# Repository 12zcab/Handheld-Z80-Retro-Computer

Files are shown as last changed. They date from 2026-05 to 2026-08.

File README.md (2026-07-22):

# A Handheld Z80 Retro Computer







Hello Im 12zcab from Hong Kong and I designed this Z80 Retro Computer :DD

# Zine Page
https://www.figma.com/design/0DzeSIebLkugrNq00bVcSF/Untitled?node-id=0-1&t=Gd1BAF2dvagKk23V-1
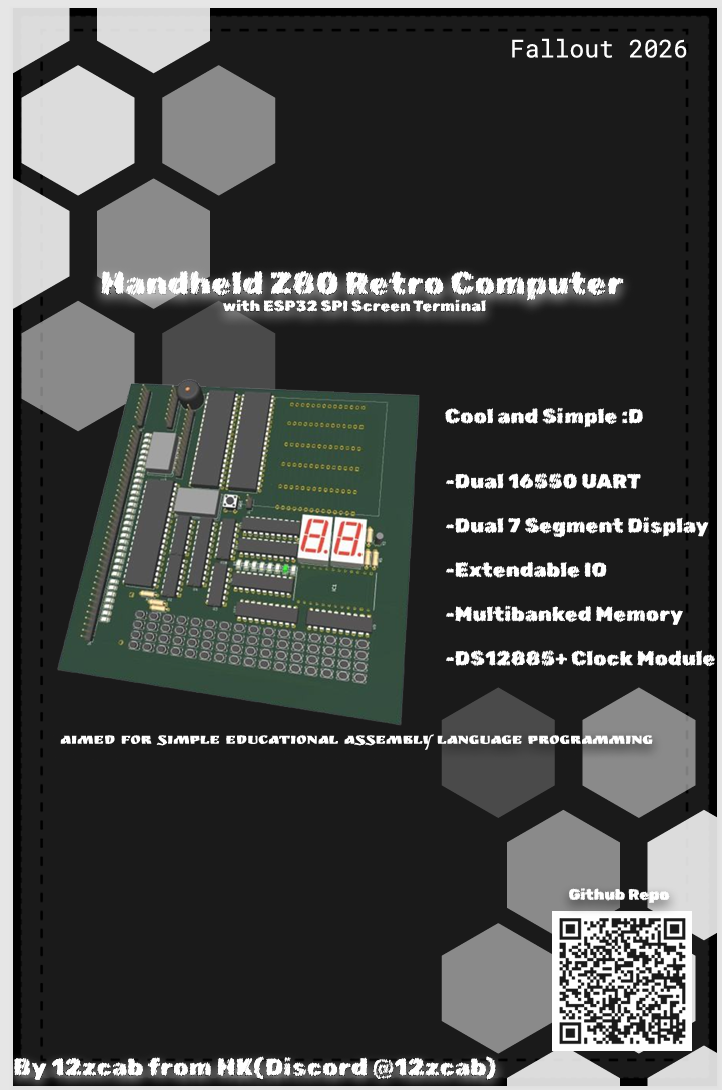
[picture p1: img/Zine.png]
Zine


# Images
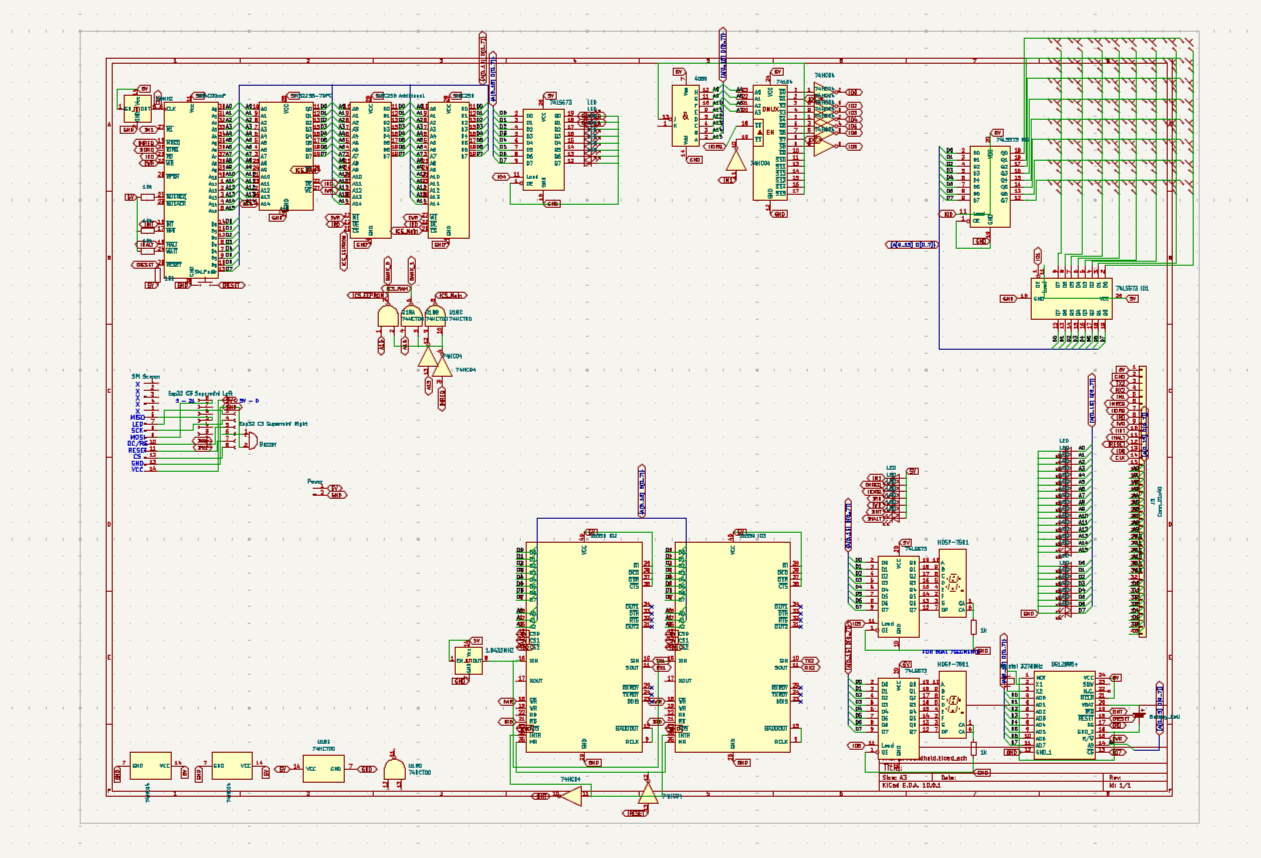
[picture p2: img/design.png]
Design

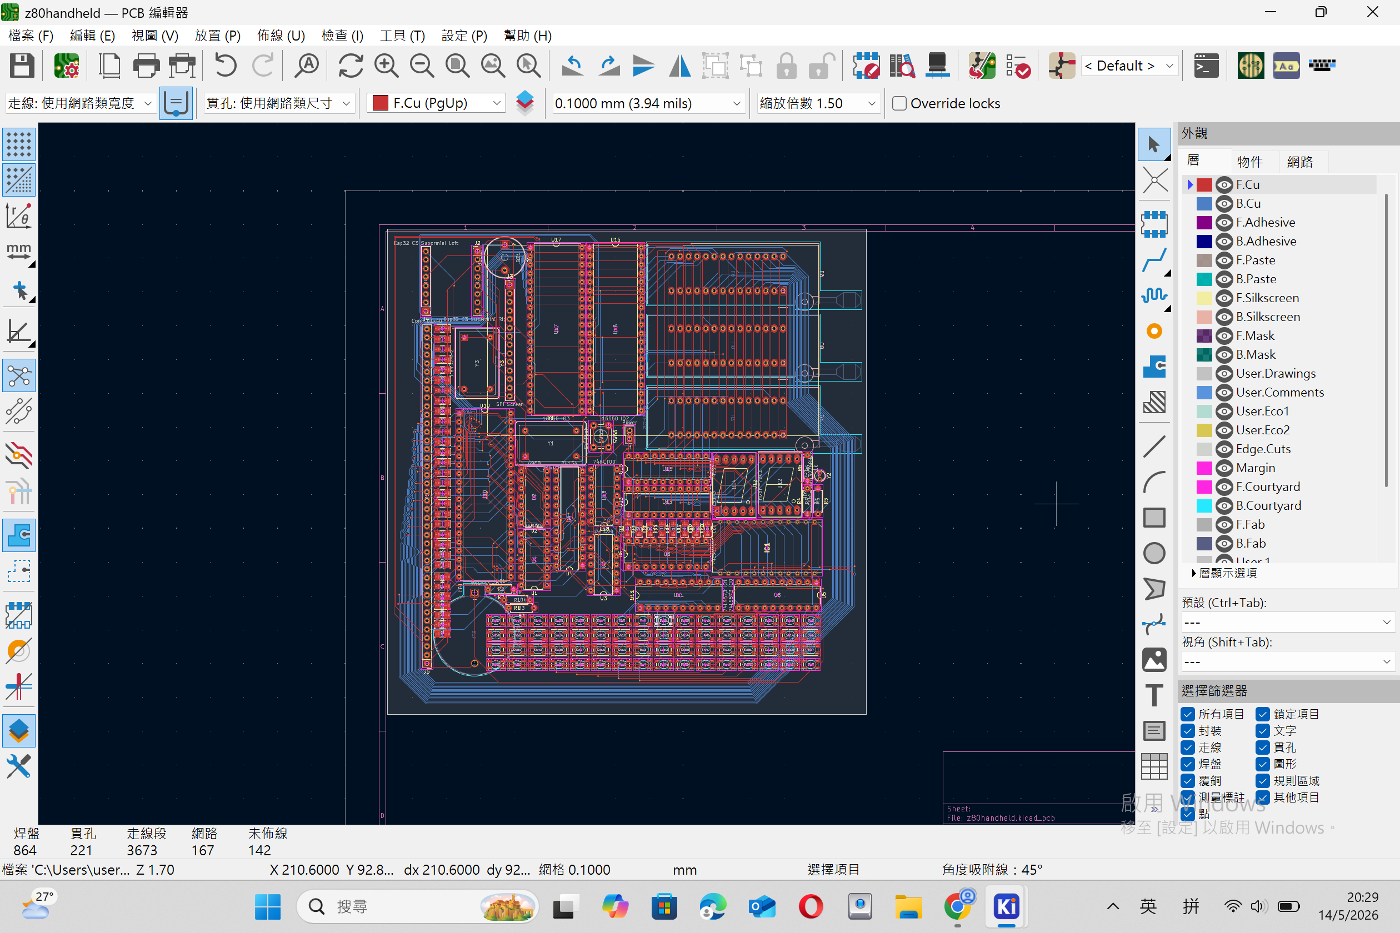
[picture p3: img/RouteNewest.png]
Route

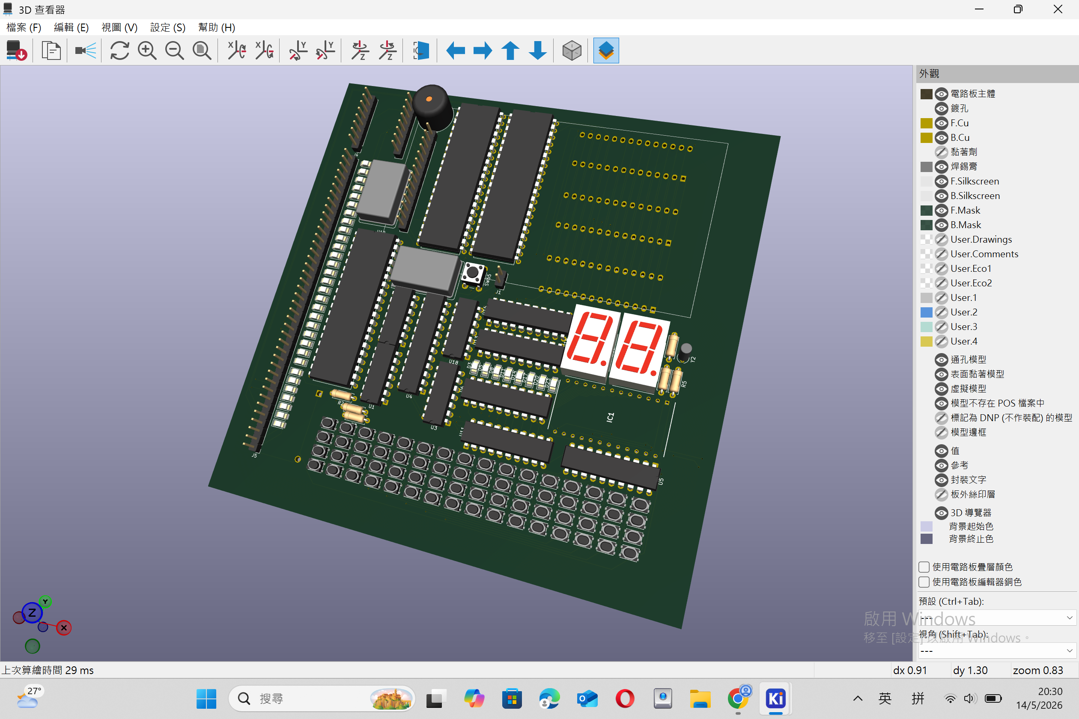
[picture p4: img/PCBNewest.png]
PCB


# What is this?
This is a portable handheld computer made with z80 customized for assembly language programming and simplified system for educational purpose.
The computer comtains a Z80 cpu,a SPI screen,a Esp32 C3 Supermini and 2 EEPROM slot,a RAM slot,a buzzer,some leds,2 7segments and a extendable port for IO.
The computer support Dual-UART communication, one with the Esp32 and one for extending.
# What it does?
It just let you run simple programs on it and let you bring it anywhere!
My final goal is to write a fully functional Operating System and make it as simple as possible on this computer!
With the ESP32 C3 Supermini connected through UART,you can draw on SPI screen and output characters just like connected to a VT100 Terminal (for old computers)
With the Buzzer,7segments and the keyboard also with the extendable port,you can build alsome retro coding projects on this old-fashion Cyberdeck :D
# Why it exists?
Erm it all started when I found a video about old pokemon games and i started to play Gen 1 pokemon games on emulators(Red Version).
I found it a really amazing experience to have play a game with greyscale and 8 bit musics.
Then I asked my parents and found that we actually have a real gameboy athome!!
I then started to research on how gameboy works and study on the Disassembled PokeRed gameboy assembly code on github and I was shocked on how elegance it is the original assembly code.
Then I learnt the gbz80 instruction set,also the boot rom of the gameboy,then also 8086,8051,8085 and z80 assembly.
I followed a youtube video and built my first z80 computer and started to do a few assembly programming on it and yah its really fun [Ytlink](https://youtu.be/A0VpPRWrqHc?si=ajm_OGpBwFbzzyzW).
I recently found Fallout Event on HackClub and instantly found this a great oppertunity to design my own real z80 computer that is simple and workable.

# Basic Structure
##Memory Map
| Address | Compoenent | Function |
|----|----|----|
|0x0000 - 0x7FFF| EEPROM | Executable Code of Operating System |
|0x8000 - 0xFEFF| RAM or EEPROM | Multibanked External EEPROM and RAM |
|0xFF00 - 0xFFFF| IO Outputs | for Output,UART,and also other Extension Usage |
|----|----|----|

# Compoenents

## Main Compoenents
| Name | Usage | Quantity |
|----|----|----|
| Z84C00xxP | The CPU of the Computer | 1 |
| ESP32 C3 Supermini | The Micro Controller Board for Serial Output Processing | 1 |
| 3.5inch SPI Screen 14Pin| For Displaying Serial Output | 1 |
| DS12885+ Clock Module | Clock Module For Z80 | 1 |
| 62256 | 32k RAM for Z80 | 1 |
| 28C256 | 32k EEPROM for External file and Bootloader and Applications | 2 |
| HDSP-7501 | 7 Segment Display for Z80 Output | 2 |
| 16550 | UART Communication IC for Z80 IO | 2 |
| PTS 810 SMD Button | Keyboard Input for Z80 | 64 |
| 4 Pin 6mm Switch | Reset Button for Z80 | 1 |
| LED SMD 1206 | SMD LED with internal resistor for Signal and Data Bus displaying | 39 |
| Buzzer | D12mm height 9.5mm with RM7.6mm Buzzer for ESP32 C3 Supermini to Emit sound when receive specific serial input from Z80 | 1 |
| CR2032 battery holder | Battery for DS12885+ Clock Module | 1 |

## Logic Gates and ICs
| Name | Usage | Quantity |
|----|----|----|
| 74HC573 | A Registor for Input and Output and Multibanking | 5 |
| 74HC04 | Hex Logic Invertor for toggling High-Activate Signals and Low-Activate Signals | 2 |
| 4068 | 8 Input AND/NAND Logic Gate for IO Signal Filtering | 1 |
| 74154 | 4 to 16 Decoder for IOS Address Decoding | 1 |
| 74HC00 | Quad NAND Gate | 2 |

## Crystals
| Name | Usage | Quantity |
|----|----|----|
| 4 Pin Crystals | 20MHz and 1.8432MHz for CPU and UART ic respectively | 2 |
| 2 Pin Crystal | 32768Hz for DS12885+ Clock Module | 1 |

## Resistors
| Name | Usage | Quantity |
|----|----|----|
| 1K resistor | 7 segment display resistor to prevent the display BURn :D | 2 |
| 10K resistor | Pull-up Resistors | 4 |

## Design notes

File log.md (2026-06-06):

Day1 18/4/2026

what will we do?

A Handheld Z80 based device with a LOTS of cool feature

1.IT MUST HAVE A KEYBOARD

2.IT HAVE A BIOS

3.IT HAVE A OPERATING SYSTEM

4.IT CAN LOAD BINARY FILES

5.IT CAN OUTPUT SOUND

6.IT MUST HAVE A SCREEN OFCOURSE EHHEEEEEEE(i think may be power with esp32 by reading UART(can receive ansi and VT350 commands))

7.IT BETTER CAN USE ESP32 TO DO INTERNET AND BLUETOOTH(DONT RELY TOO MUCH THOUGH...)

8.it can connect UART to computer :D 16550UART CHIP

9.better connect a tfcard

welp today lets make a really simple z80 circuit that can read from a eeprom when start :D

Memory

0x0000 to 0x7FFF 32kb BIOS + Program EEPROM (first half writable but second half is not.)

0x8000 to 0xFFFF 32kbRAM and 32kb ROM (Paged)

0xFF00 to 0xFFFsF Input and Output

what i need to do:

1.finish the Double UART

2.finish the SPI Screen and the esp32 c3 supermini

3\. finish the eeprom and ram

4\. write a simple bios

5.write a test program

6.add a 7segment led output io module

7.add some controllable pins for further extend

Day 2 19/4/2026

OHH YAEAH ITS OUR second day erm unfortunately i  dont really have much time today but nvm lets complete the UART thing first :D

what ive done:

1.UART

2.SPI screen

3.buzzer

4.Multibanking chip achieved with 573

what i need to do:

1\. finish the eeprom and ram
2\. write a simple bios
3\. write a test program
4\. add a 7segment led output io module
5\. add some controllable pins for further extend
6\. add status leds
7\. reset,halt,resume button(if needed i guess)
8\. controllable leds to fully utilize the 573 for multi banking

Part2

what ive done:

1.banking logic (totally)
2.searching for how z80 interrupt and halt and wait works.

what i need to do:

1. write a simple bios
2. write a test program
3. add some controllable pins for further extend
4. add status leds
5. reset,halt,resume button(if needed i guess)

Day 3 20/4/2026

what i will do today:

1. finish the status leds
2. add some controllable pins
3. reset halt and resume :D
 after some consideration i think i will just abandon the interrupt as humm I WRITE THE CODE I WRITE THE PROGRAMS NAD I DESIGN IT :D so i think i dont need them :DDDDD:D:D:DD:D:DDDDDDDDDDDDDDDDDDD

what ive done:
1. all of the schematics
2. layout the keyboard and led and spiscreen for the pcb

what i need to do:

1. write a simple bios
2. write a test program
3. layout the pcb

Day 4 21/4/2026

what ive done today:
1.layout the pcb
2.route the pcb(yah sorry with autoroute cuz my routing technique is kinda bad)

what i need to do:
1.write a bootloader
2.write a test program
3.write a program for esp32 to display serial datas

Day 5 22/4/2026

what ive done today:
1.rerouted the pcb (bruh Freeroute is terrible)
2.added the extension port
3.wrote something on the README.md

Day 6 23/4/2026

what ive done today:
1.edited the README.md to add the components list
2.autorouted AGAIIINNN with Electra and THATS WAS AMAZING OMG ITS SOOOOO COOL

Day 7 24/4/2026

what ive done today:
1.Wrote file for Programming on the Computer.
2.Fixed a wiring problem on PCB(Not Logic Gate Inverted for the interrupt Signal 16550) and reroute the wiring again.

Day 8 25/4/2026

what ive done today:
1.Finished the Programmer Manual

Day 9 1/5/2026

what ive done today:
1.Simplified the Multibank Circuit (Reduced SMD usage)
2.Rerouted the pcb again for the modification made
(I Tried EAGLE,AutoRoute,and even asked Ai to help me write a simple autoroute application but erm in the end i used electra :| electra is amazing...)

Day 10 3/5/2026

what ive done today:
Wrote a Script for the Video
Updated the BOM list
Updated the Documentation
Started to create the project video

Day 11 12 4/5/2026 and 5/5/2026

Human Reroute again and again :D

Day 13 7/5/2026
Wrote some assembly for Memory loading and 7 segment output and searched for how to write those assembly and tested on ASM80.com

Day 14-15 8/5/2026 9/5/2026
Continued to route the PCB

Day 16 11/5/2026
I realized the layout that I designed for the PCB was already wrong from the start...
the Layout is too terrible and too hard to route (why there are so many signals wiring that need to be routed across the whole board XDDDDDD)
Yah I redesigned the layout and i think now the layout is much more cleaner :D
the Interrupt Signals and the ReadWriteChipSelect signals are still hard to route though but the Data buses and Address buses are much better :D

Day 17 12/5/2026
humm actually the current layout is still not yet the best one but i think i will keep the current one and try to add more space for me to route by pushing a bit the edges :D

Day 1819 13-14/5/2026
FINISHED ROUTING PART and Re-Upload for review again :D

Day 20 6/6/2026
Edited the BOM and resubmitted for Review

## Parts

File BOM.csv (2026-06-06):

Type | Component Name | Usage | Quantity | Link | Price for 1 In RMB | Total Price In RMB | Total Price In USD
Main Component | Z84C00xxP | The CPU of the Computer | 1 | https://item.taobao.com/item.htm?id=761285443532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 | 4 | 4 | 0.6
Main Component | ESP32 C3 Supermini | The Micro Controller Board for Serial Output Processing | 1 | https://item.taobao.com/item.htm?id=811195319483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 | 9.2 | 9.2 | 1.38
Main Component | 3.5inch SPI Screen 14Pin | For Displaying Serial Output | 1 | https://item.taobao.com/item.htm?id=812167177326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 | 52.47 | 52.47 | 7.8705
Main Component | DS12885+ Clock Module | Clock Module For Z80 | 1 | https://item.taobao.com/item.htm?id=724760924535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 | 10 | 10 | 1.5
Main Component | 62256 | 32k RAM for Z80 | 1 | https://item.taobao.com/item.htm?id=762350642485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 | 3.8 | 3.8 | 0.57
Main Component | 28C256 | 32k EEPROM for External file and Bootloader and Applications | 2 | https://item.taobao.com/item.htm?id=772254803732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 | 11.9 | 23.8 | 3.57
Main Component | THT 7 Segment Display | 7 Segment Display for Z80 Output | 2 | https://item.taobao.com/item.htm?id=554338007716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 | 3.6 | 7.2 | 1.08
Main Component | 16550 UART | Communication IC for Z80 IO | 2 | https://item.taobao.com/item.htm?id=923571185900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 | 8.5 | 17 | 2.55
Main Component | PTS 810 SMD Button | Keyboard Input for Z80 | 64 | https://item.taobao.com/item.htm?id=942210332853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 | (for 70) | 17.5 | 2.625
Main Component | 4 Pin 6mm Switch | Reset Button for Z80 | 1 | https://item.taobao.com/item.htm?id=705965507255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 | 7.78 | 7.78 | 1.167
Main Component | LED SMD 1206 | SMD LED with internal resistor for Signal and Data Bus displaying | 39 | https://item.taobao.com/item.htm?ali_trackid=282_2fcfaf0dd0fba5e6a350743651408552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 | 2.43 (for 50) | 2.43 | 0.3645
Main Component | Buzzer D12mm | Buzzer for ESP32 C3 to Emit sound | 1 | https://item.taobao.com/item.htm?ali_trackid=282_46b06612243efc37df9fef9a8941b055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 | 0.23 | 0.23 | 0.0345
Main Component | CR2032 battery holder | Battery for DS12885+ Clock Module | 1 | https://item.taobao.com/item.htm?ali_trackid=282_1583c703d73fba8a7dc9987e7ff74949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 | 0.05 | 0.05 | 0.0075
Logic IC | 74HC573 | A Register for Input and Output and Multibanking | 5 | https://item.taobao.com/item.htm?id=600787711706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 | 0.44 | 2.2 | 0.33
Logic IC | 74HC04 | Hex Logic Invertor for toggling High/Low Signals | 2 | https://item.taobao.com/item.htm?id=641847178827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 | 1.1 (for 2) | 1.1 | 0.165
Logic IC | 4068 | 8 Input AND/NAND Logic Gate for IO Signal Filtering | 1 | https://item.taobao.com/item.htm?id=594087066444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 | 4.2 | 4.2 | 0.63
Logic IC | 74154 | 4 to 16 Decoder for IOS Address Decoding | 1 | https://item.taobao.com/item.htm?id=604348655487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 | 2.9 | 2.9 | 0.435
Logic IC | 74HC00 | Quad NAND Gate | 2 | https://item.taobao.com/item.htm?id=40637073384&skuId=4862704224150 | 0.24 | 0.48 | 0.072
Crystal | 4 Pin Crystal 20MHz | CPU Clock | 1 | https://item.taobao.com/item.htm?id=611471253289&from=cart&skuId=4475562482029&upStreamPrice=435 | 4.2 | 4.2 | 0.63
Crystal | 4 Pin Crystal 1.8432MHz | UART Clock | 1 | https://detail.tmall.com/item.htm?from=cart&id=611471253289&skuId=4475562482037&upStreamPrice=435 | 4.2 | 4.2 | 0.63
Crystal | 2 Pin Crystal 32768Hz | For DS12885+ Clock Module | 1 | https://item.taobao.com/item.htm?id=522556171403&from=cart&upStreamPrice=242 | 2.42 | 2.42 | 0.363
Resistor | 1K resistor | 7 segment display resistor | 2 | https://item.taobao.com/item.htm?id=809415019964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 | 6.77 | 13.54 | 2.031
Resistor | 10K resistor | Pull-up Resistors | 4 | same as 1k one. | 0 | 0 | 0
OtherParts | DIP sockets | PinSockets for all DIP components
OtherParts | 2.54 Dupont PinSockets and PinHeaders | for ESP32 and Screen
Total Components |  |  |  |  |  |  | 28.605
Estimated PCB fee and PCBA service fee |  |  |  |  |  |  | 15
Estimated Shipping fee |  |  |  |  |  |  | 4.3605
Total Cost |  |  |  |  |  |  | 47.9655

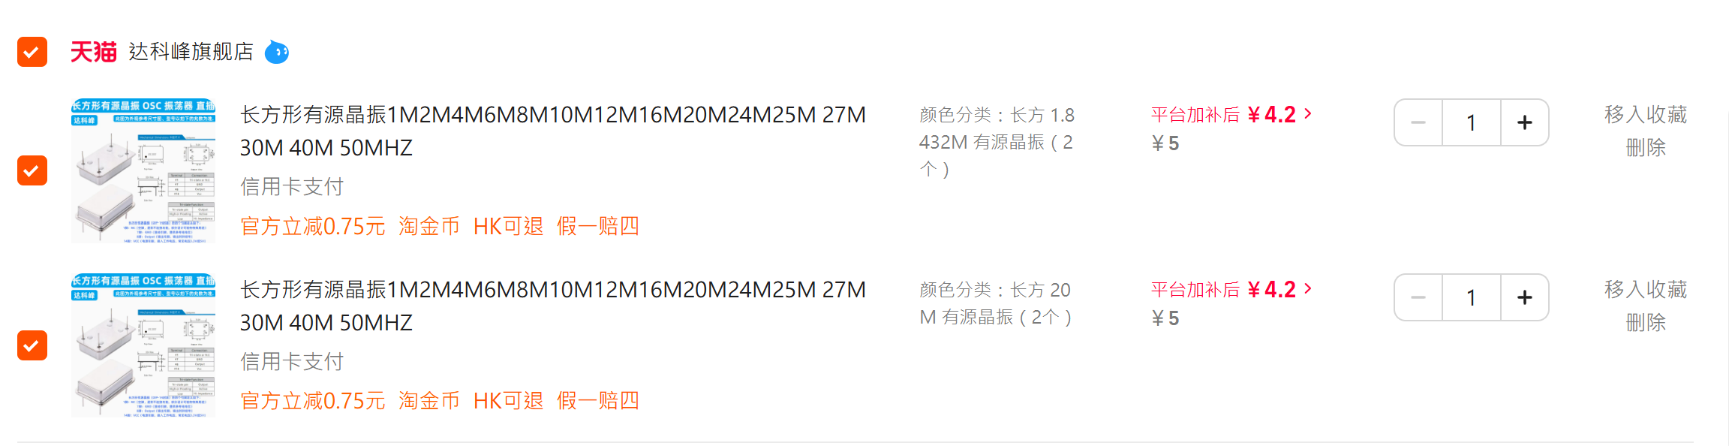
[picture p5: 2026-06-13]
ShoppingCartIMG/螢幕擷取畫面 2026-06-13 230437.png

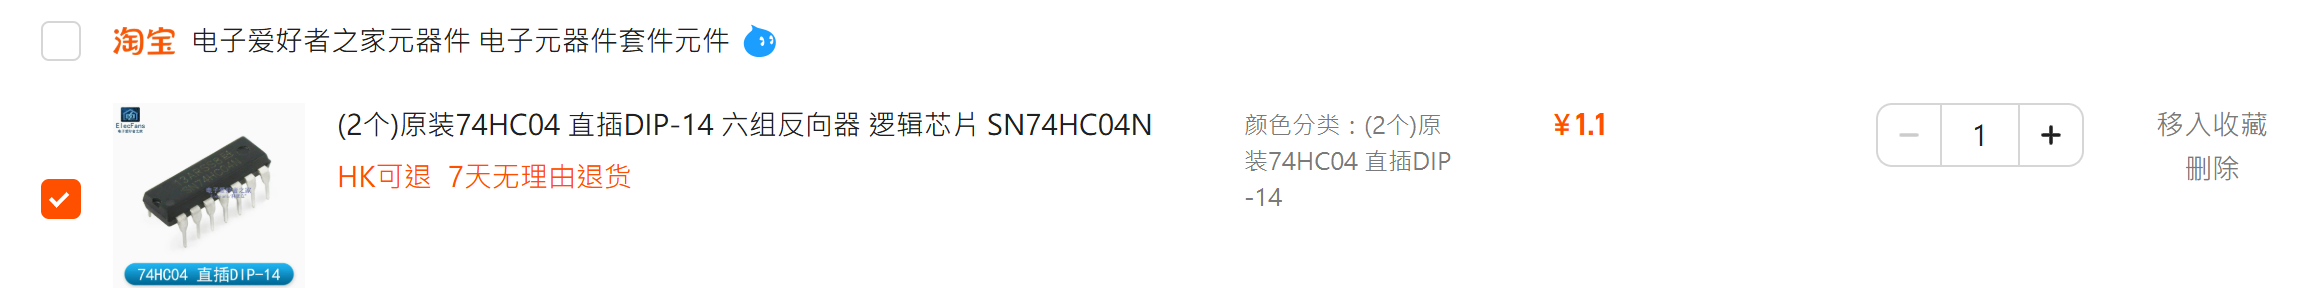
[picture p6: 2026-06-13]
ShoppingCartIMG/螢幕擷取畫面 2026-06-13 230454.png

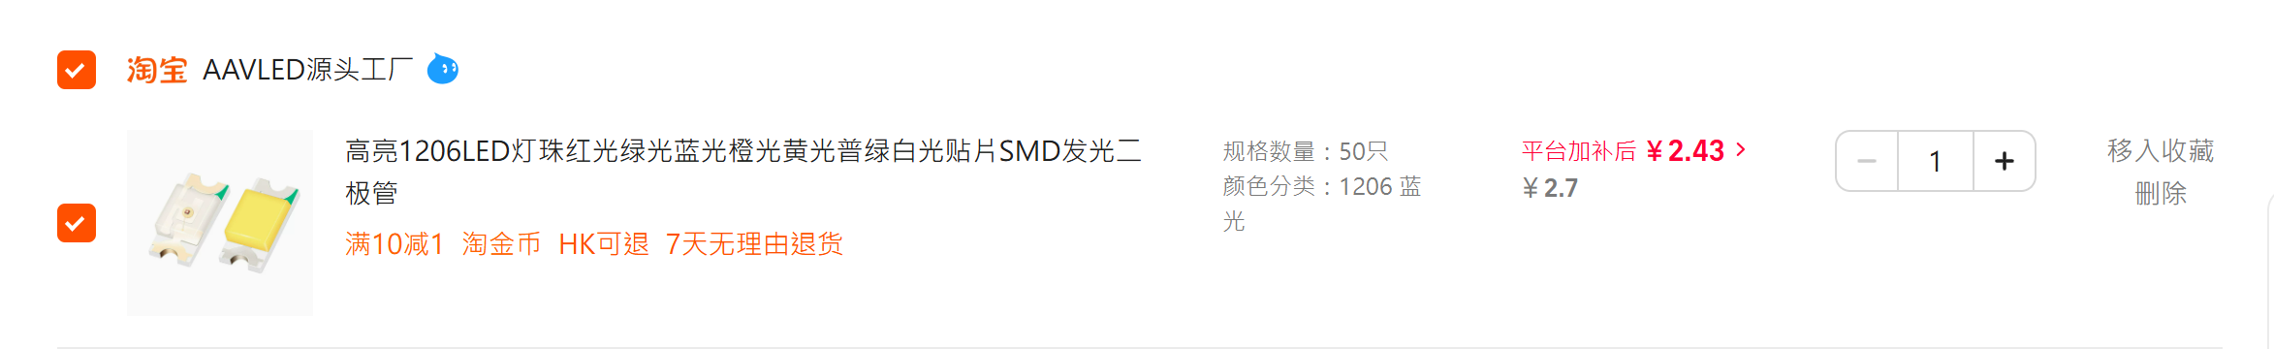
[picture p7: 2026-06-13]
ShoppingCartIMG/螢幕擷取畫面 2026-06-13 230503.png

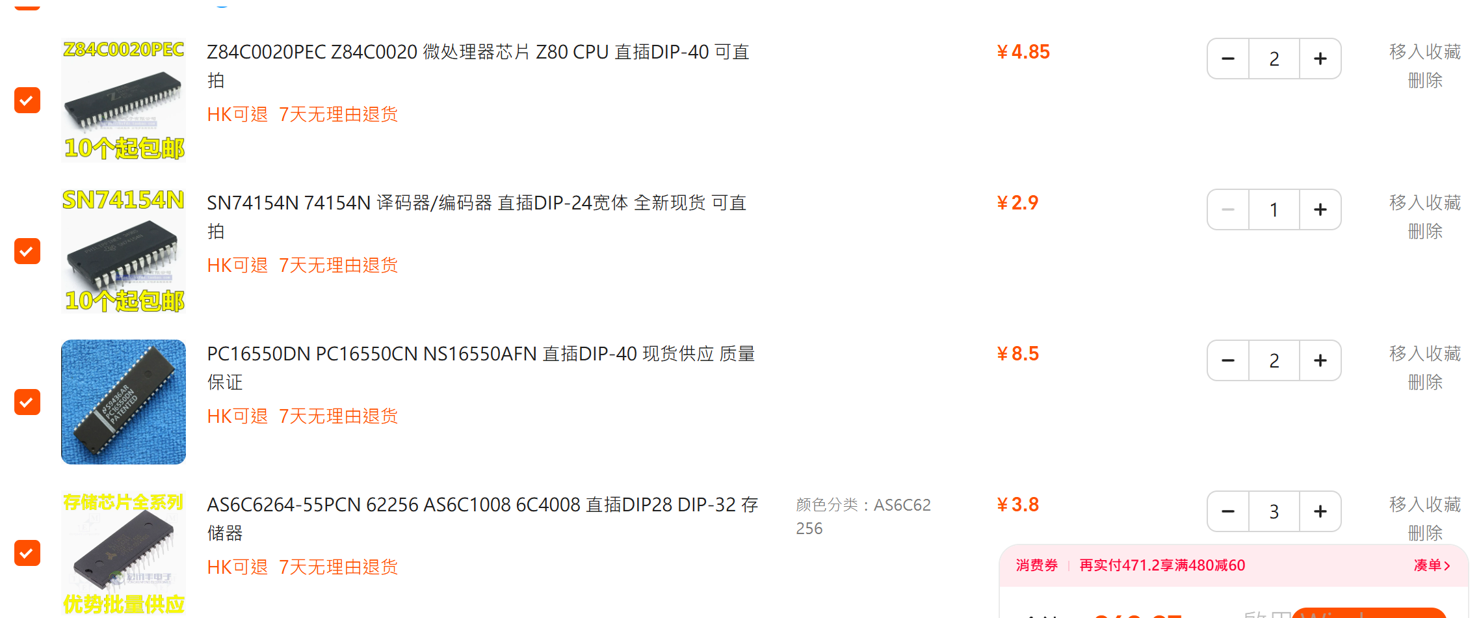
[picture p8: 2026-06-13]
ShoppingCartIMG/螢幕擷取畫面 2026-06-13 230402.png

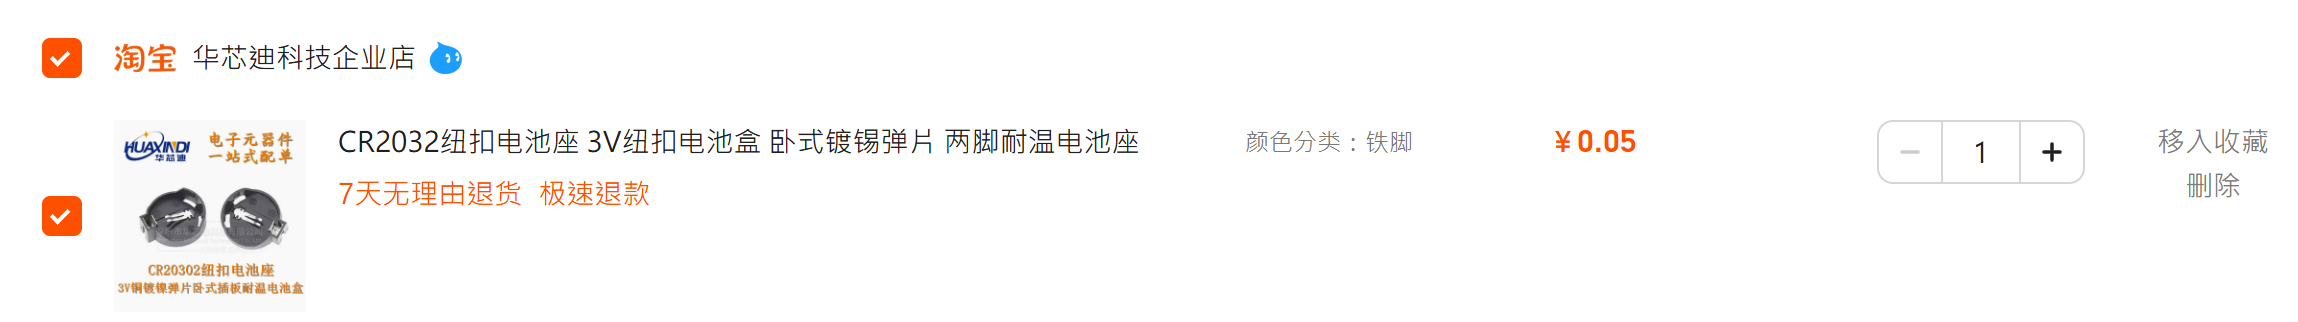
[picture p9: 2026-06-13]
ShoppingCartIMG/螢幕擷取畫面 2026-06-13 230457.png

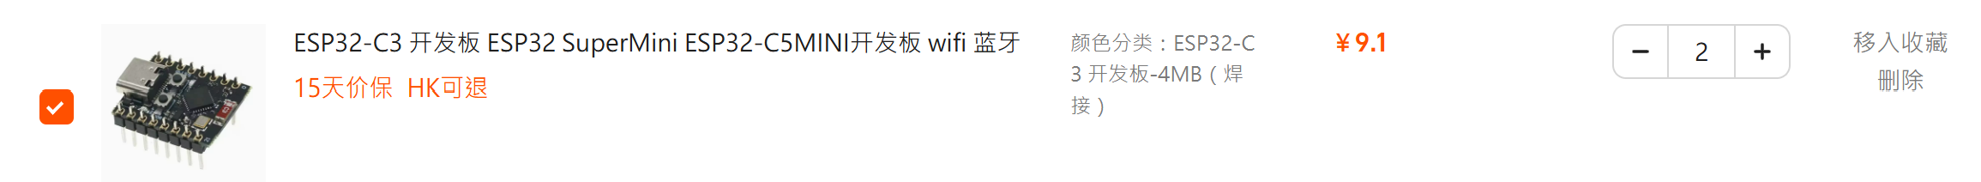
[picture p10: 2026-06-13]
ShoppingCartIMG/螢幕擷取畫面 2026-06-13 230516.png

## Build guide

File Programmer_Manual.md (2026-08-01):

# Features

1.UART
2.Multibank RAM/EEPROM and Status LED Output
3.DS12885+ Clock Module
4.Keyboard
5.7 Segments
6.Extend IO Port

# UART Programming [Reference Document](https://forum.mapleboard.org/topic/uart8250-%252525E8%25252588%25252587-ns16550-%252525E6%252525B7%252525B1%252525E5%25252585%252525A5%252525E5%25252589%25252596%252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)
The computer uses dual 16550 UART IC for UART communication.
The main 16550 is on IO Address 0xFF20 and the other one is on IO Address 0xFF30
The main 16550 is dedicated for Terminal Display and Internet function with ESP32 on board while the other one is free to use it any way you want.

16550 Have 3 Address Lines for 8 Registers.
It have 2 Modes depending on the DLAB set.(Bit 7 for Register 0b011)

```z80asm
; Assume we wanna write to ESP32
UART_ADDR EQU 0xFF20

; Registers
; Receive Buffer Register
UART_RBR   EQU UART_ADDR + 0
; Transmitter Holding Register
UART_THR   EQU UART_ADDR + 0
; Interrupt Enable Register
UART_IER   EQU UART_ADDR + 1
; FIFO Control Register
UART_FCR   EQU UART_ADDR + 2
; Line Control Register
UART_LCR   EQU UART_ADDR + 3
;Line Status Register
UART_LSR   EQU UART_ADDR + 5

; 1. Set DLAB (Divisor Latch Access Bit)
ld a, 80h       ; DLAB = 1
out (UART_LCR), a

; 2. Set Baud Rate (1.8432 MHz crystal, 9600 baud)
; Divisor = 1843200 / (16 * 9600) = 12 (0x0C)
ld a, 0Ch
out (UART_ADDR + 0), a ; LSB
ld a, 00h
out (UART_ADDR + 1), a ; MSB

; 3. Clear DLAB, set 8N1 (8 data bits, no parity, 1 stop bit)
ld a, 03h
out (UART_LCR), a

; 4. Enable FIFOs (16550 Specific)
ld a, 07h       ; Enable RX/TX FIFOs and reset them
out (UART_FCR), a

send_char:
    in a, (UART_LSR) ; Read Line Status Register
    bit 5, a         ; Test bit 5 (Transmitter Holding Register Empty)
    jr z, send_char  ; Loop if 0 (busy)
    ld a, 'A'        ; Character to send
    out (UART_THR), a
    ret

receive_char:
    in a, (UART_LSR) ; Read Line Status Register
    bit 0, a         ; Test bit 0 (Data Ready)
    jr z, receive_char ; Loop if 0 (no data)
    in a, (UART_RBR) ; Read received byte
    ret

```

# Multibank RAM/EEPROM and Status LED Programming
It's just basically a 74hc573 on IO Port 4(0xFF40).
Bit 0: Low_Activate ChipSelect Signal for 32k RAM on address 0x8000 to 0xFEFF
Bit 1: Low_Activate ChipSelect Signal for EEPROM on address 0x8000 to 0xFEFF
Bit 2-7: Status LED on board

```z80asm
; Define IO Address
BANK_REG   EQU 0xFF40

; Enable EEPROM and Disable RAM and Turn Off all LEDs
ld a, 01h
out (BANK_REG), a

; Enable RAM and Disable EEPROM and Turn On all LEDs
ld a, FEh
out (BANK_REG), a
```
# ALERT DURING BUILDING STAGE I FOUND THIS CODE IS ACTUALLY WRONG, WE SHOULD LOAD FF40 to BC first then OUT (C),A

# DS12885+ Clock Module Programming [Reference Document](https://www.analog.com/media/en/technical-documentation/data-sheets/DS12885-DS12C887A.pdf)
It's on the IO  Port of the Z80.
The Clock Module have two modes : BCD Mode and Binary Mode

### Table 2A. Time, Calendar, and Alarm Data Modes—BCD Mode (DM = 0)

| ADDRESS | BIT 7 | BIT 6 | BIT 5 | BIT 4 | BIT 3 | BIT 2 | BIT 1 | BIT 0 | FUNCTION | RANGE |
| :--- | :---: | :---: | :---: | :---: | :---: | :---: | :---: | :---: | :--- | :--- |
| 00H | 0 | \<- | 10 Seconds | -> | \<- | Seconds | -> | | Seconds | 00–59 |
| 01H | 0 | \<- | 10 Seconds | -> | \<- | Seconds | -> | | Seconds Alarm | 00–59 |
| 02H | 0 | \<- | 10 Minutes | -> | \<- | Minutes | -> | | Minutes | 00–59 |
| 03H | 0 | \<- | 10 Minutes | -> | \<- | Minutes | -> | | Minutes Alarm | 00–59 |
| 04H | AM/PM | 0 | 10 Hours | | \<- | Hours | -> | | Hours | 1–12 +AM/PM / 00–23 |
| 05H | AM/PM | 0 | 10 Hours | | \<- | Hours | -> | | Hours Alarm | 1–12 +AM/PM / 00–23 |
| 06H | 0 | 0 | 0 | 0 | 0 | \<- | Day | -> | Day | 01–07 |
| 07H | 0 | 0 | \<- | 10 Date | \<- | Date | -> | | Date | 01–31 |
| 08H | 0 | 0 | 0 | 10 Mo. | \<- | Month | -> | | Months | 01–12 |
| 09H | \<- | 10 Years | -> | | \<- | Year | -> | | Year | 00–99 |
| 0AH | UIP | DV2 | DV1 | DV0 | RS3 | RS2 | RS1 | RS0 | Control | — |
| 0BH | SET | PIE | AIE | UIE | SQWE | DM | 24/12 | DSE | Control | — |
| 0CH | IRQF | PF | AF | UF | 0 | 0 | 0 | 0 | Control | — |
| 0DH | VRT | 0 | 0 | 0 | 0 | 0 | 0 | 0 | Control | — |
| 0EH-31H | X | X | X | X | X | X | X | X | RAM | — |
| 32H | \<- | 10 Century | -> | | \<- | Century* | -> | | Century* | 00–99 |
| 33H-7FH | X | X | X | X | X | X | X | X | RAM | — |
---

### Table 2B. Time, Calendar, and Alarm Data Modes—Binary Mode (DM = 1)

| ADDRESS | BIT 7 | BIT 6 | BIT 5 | BIT 4 | BIT 3 | BIT 2 | BIT 1 | BIT 0 | FUNCTION | RANGE |
| :--- | :---: | :---: | :---: | :---: | :---: | :---: | :---: | :---: | :--- | :--- |
| 00H | 0 | 0 | \<- | -> | Seconds | <- | -> | | Seconds | 00–3B |
| 01H | 0 | 0 | \<- | -> | Seconds | <- | -> | | Seconds Alarm | 00–3B |
| 02H | 0 | 0 | \<- | -> | Minutes | <- | -> | | Minutes | 00–3B |
| 03H | 0 | 0 | \<- | -> | Minutes | <- | -> | | Minutes Alarm | 00–3B |
| 04H | AM/PM | 0 | 0 | \<- | -> | Hours | <- | -> | Hours | 01–0C +AM/PM / 00–17 |
| 05H | AM/PM | 0 | 0 | \<- | -> | Hours | <- | -> | Hours Alarm | 01–0C +AM/PM / 00–17 |
| 06H | 0 | 0 | 0 | 0 | 0 | \<- | Day | -> | Day | 01–07 |
| 07H | 0 | 0 | 0 | \<- | -> | Date | <- | -> | Date | 01–1F |
| 08H | 0 | 0 | 0 | 0 | \<- | -> | Month | | Months | 01–0C |
| 09H | 0 | \<- | -> | Year | <- | -> | <- | -> | Year | 00–63 |
| 0AH | UIP | DV2 | DV1 | DV0 | RS3 | RS2 | RS1 | RS0 | Control | — |
| 0BH | SET | PIE | AIE | UIE | SQWE | DM | 24/12 | DSE | Control | — |
| 0CH | IRQF | PF | AF | UF | 0 | 0 | 0 | 0 | Control | — |
| 0DH | VRT | 0 | 0 | 0 | 0 | 0 | 0 | 0 | Control | — |
| 0EH-31H | X | X | X | X | X | X | X | X | RAM | — |
| 32H | N/A | N/A | \<- | -> | Century* | <- | -> | | Century* | — |
| 33H-7FH | X | X | X | X | X | X | X | X | RAM | — |

---

**Notes:**
* **X** = Read/Write Bit.
* **\*** = DS12C887, DS12C887A only. General-purpose RAM on DS12885, DS12887, and DS12887A.
* **Note**: Unless otherwise specified, the state of the registers is not defined when power is first applied. Except for the seconds register, 0 bits in the time and date registers can be written to 1, but may be modified when the clock updates. 0 bits should always be written to 0 except for alarm mask bits.

```z80asm
; =====================================================================
; DS12885+ REAL TIME CLOCK DRIVER (Z80)
; Port Mapping:
; FF71h -> AS High (Address Strobe High)
; FF70h -> AS Low  (Latch Address / Data Access)
; =====================================================================

; --- Port Definitions ---
RTC_CMD      EQU 0FF71h    ; Port with A0=1 (AS High)
RTC_DATA     EQU 0FF70h    ; Port with A0=0 (AS Low)

; --- Internal Register Map ---
RTC_SEC      EQU 00h       ; Seconds
RTC_MIN      EQU 02h       ; Minutes
RTC_HOUR     EQU 04h       ; Hours
RTC_DAY_WEEK EQU 06h       ; Day of week (1-7)
RTC_DAY_MON  EQU 07h       ; Day of month (1-31)
RTC_MONTH    EQU 08h       ; Month (1-12)
RTC_YEAR     EQU 09h       ; Year (00-99)
RTC_REG_A    EQU 0Ah       ; Status Register A
RTC_REG_B    EQU 0Bh       ; Status Register B

; =====================================================================
; INITIALIZATION: Setup Oscillator and 24-Hour BCD Mode
; =====================================================================
INIT_RTC:
    ; 1. Setup Register A: Turn on the 32.768kHz oscillator
    LD A, RTC_REG_A
    CALL SELECT_REG
    LD A, 00100000b       ; DV2-0 = 010 (Osc On), RS3-0 = 0000 (None)
    OUT (C), A

    ; 2. Setup Register B: 24Hr mode, BCD format, Daylight Savings Off
    LD A, RTC_REG_B
    CALL SELECT_REG
    LD A, 00000010b       ; DM=0 (BCD), 24/12=1 (24Hr), DSE=0
    OUT (C), A
    RET

; =====================================================================
; READ TIME: Safely reads Seconds, Minutes, and Hours
; Returns: H = Hours, D = Minutes, E = Seconds (all BCD)
; =====================================================================
GET_TIME:
    ; Step 1: Wait for Update-In-Progress (UIP) bit to be clear
    ; This ensures we don't read data while the clock is updating.
WAIT_RTC:
    LD A, RTC_REG_A
    CALL SELECT_REG
    IN A, (C)
    AND 80h               ; Check bit 7 (UIP)
    JR NZ, WAIT_RTC       ; Loop if update is in progress

    ; Step 2: Read values
    LD A, RTC_SEC
    CALL SELECT_REG
    IN E, (C)             ; E = Seconds

    LD A, RTC_MIN
    CALL SELECT_REG
    IN D, (C)             ; D = Minutes

    LD A, RTC_HOUR
    CALL SELECT_REG
    IN H, (C)             ; H = Hours
    RET

; =====================================================================
; WRITE TIME: Set clock to 14:05:00 (Example)
; =====================================================================
SET_TIME_EXAMPLE:
    ; 1. Enter "Set Mode" (Stop updates)
    LD A, RTC_REG_B
    CALL SELECT_REG
    LD A, 10000010b       ; Set SET bit (7) to 1
    OUT (C), A

    ; 2. Write New Time (14:05:00)
    LD A, RTC_SEC
    CALL SELECT_REG
    LD A, 00h
    OUT (C), A

    LD A, RTC_MIN
    CALL SELECT_REG
    LD A, 05h
    OUT (C), A

    LD A, RTC_HOUR
    CALL SELECT_REG
    LD A, 14h             ; 2 PM in BCD
    OUT (C), A

    ; 3. Exit "Set Mode" (Resume updates)
    LD A, RTC_REG_B
    CALL SELECT_REG
    LD A, 00000010b       ; Clear SET bit
    OUT (C), A
    RET

; =====================================================================
; HELPER: Multiplexed Address Latch
; Input: A = Register Index
; Output: BC = RTC_DATA port address for subsequent IN/OUT
; =====================================================================
SELECT_REG:
    LD BC, RTC_CMD        ; A0 = 1 (AS High)
    OUT (C), A            ; Put index on data bus
    LD BC, RTC_DATA       ; A0 = 0 (AS High-to-Low transition)
    OUT (C), A            ; Address is now latched inside DS12885
    RET

```

# Keyboard Programming
Keyboard is connected to two 74hc573s,IO Port 0 (0xFF00) for Row Select and IO Port 1(0xFF10) for Column Read.
Although the keyboard is wired as a 8x8 matrix,the layout on the PCB is 16*4.
Please refer to the KiCad Design before programming as the layout is a bit hard to describe in pure text document.
Note that as no diodes are connected to the keyboard circuit, multiple(more than two) keypress may cause glitched input
```z80asm
COL   EQU 0xFF00
ROW   EQU 0xFF10
; Select Column
LD A,01h
OUT (COL),A
; Read Row
IN A,(ROW)
```
# 7 Segment Display Programming
7 Segment Display is on IO Port 5 and 6.(0xFF50 and 0xFF60)
```z80asm
LEFT_SEVEN_SEG   EQU 0xFF50
RIGHT_SEVEN_SEG   EQU 0xFF60

;Display qp on the seven segment displays
;Bit 0-7 for A-G and DP respectively
;Letter q:abcfg
;Letter p:abefg
;Their Binary Representation:0b11100110 and 0b11001110 (E6h and h respectively)
LD A,E6h
OUT (LEFT_SEVEN_SEG),A

LD A,CEh
OUT (RIGHT_SEVEN_SEG),A
```
# Extend IO Port Programming
The extend IO Port(2.54 Connector PinHead 40pin)
| PinNum.(From left to right,Start from 1) | PinName |
| ---- | ---- | ---- |
| 1 | 5V |
| 2 | GND |
| 3 | TX2 |
| 4 | RX2 |
| 5 | !M1 |
| 6 | !MREQ |
| 7 | !IORQ |
| 8 | !RD |
| 9 | !WR |
| 10 | !INT |
| 11 | !HALT |
| 12 | !RESET |
| 13 | IO8 |
| 14 | CLK |
| 16-31 | A0-A15 |
| 33-40 | D0-D7 |

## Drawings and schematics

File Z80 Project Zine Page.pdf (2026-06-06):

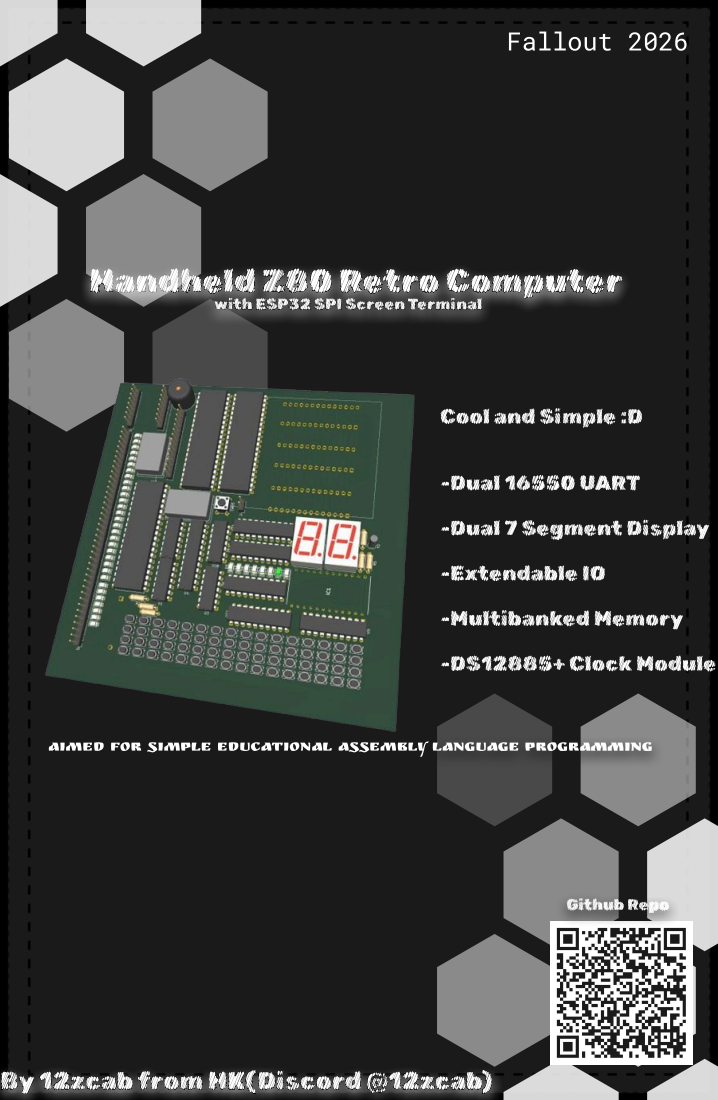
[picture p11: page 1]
Fallout 2026; -Dual 16550 UART; -Extendable IO; -Multibanked Memory; -DS12885+ Clock Module; Github Repo

Handheld Z80 Retro Computer with ESP32 SPI Screen Terminal

Cool and Simple :D

-Dual 7 Segment Display

Aimed for simple educational Assembly language programming

By 12zcab from HK(Discord @12zcab)

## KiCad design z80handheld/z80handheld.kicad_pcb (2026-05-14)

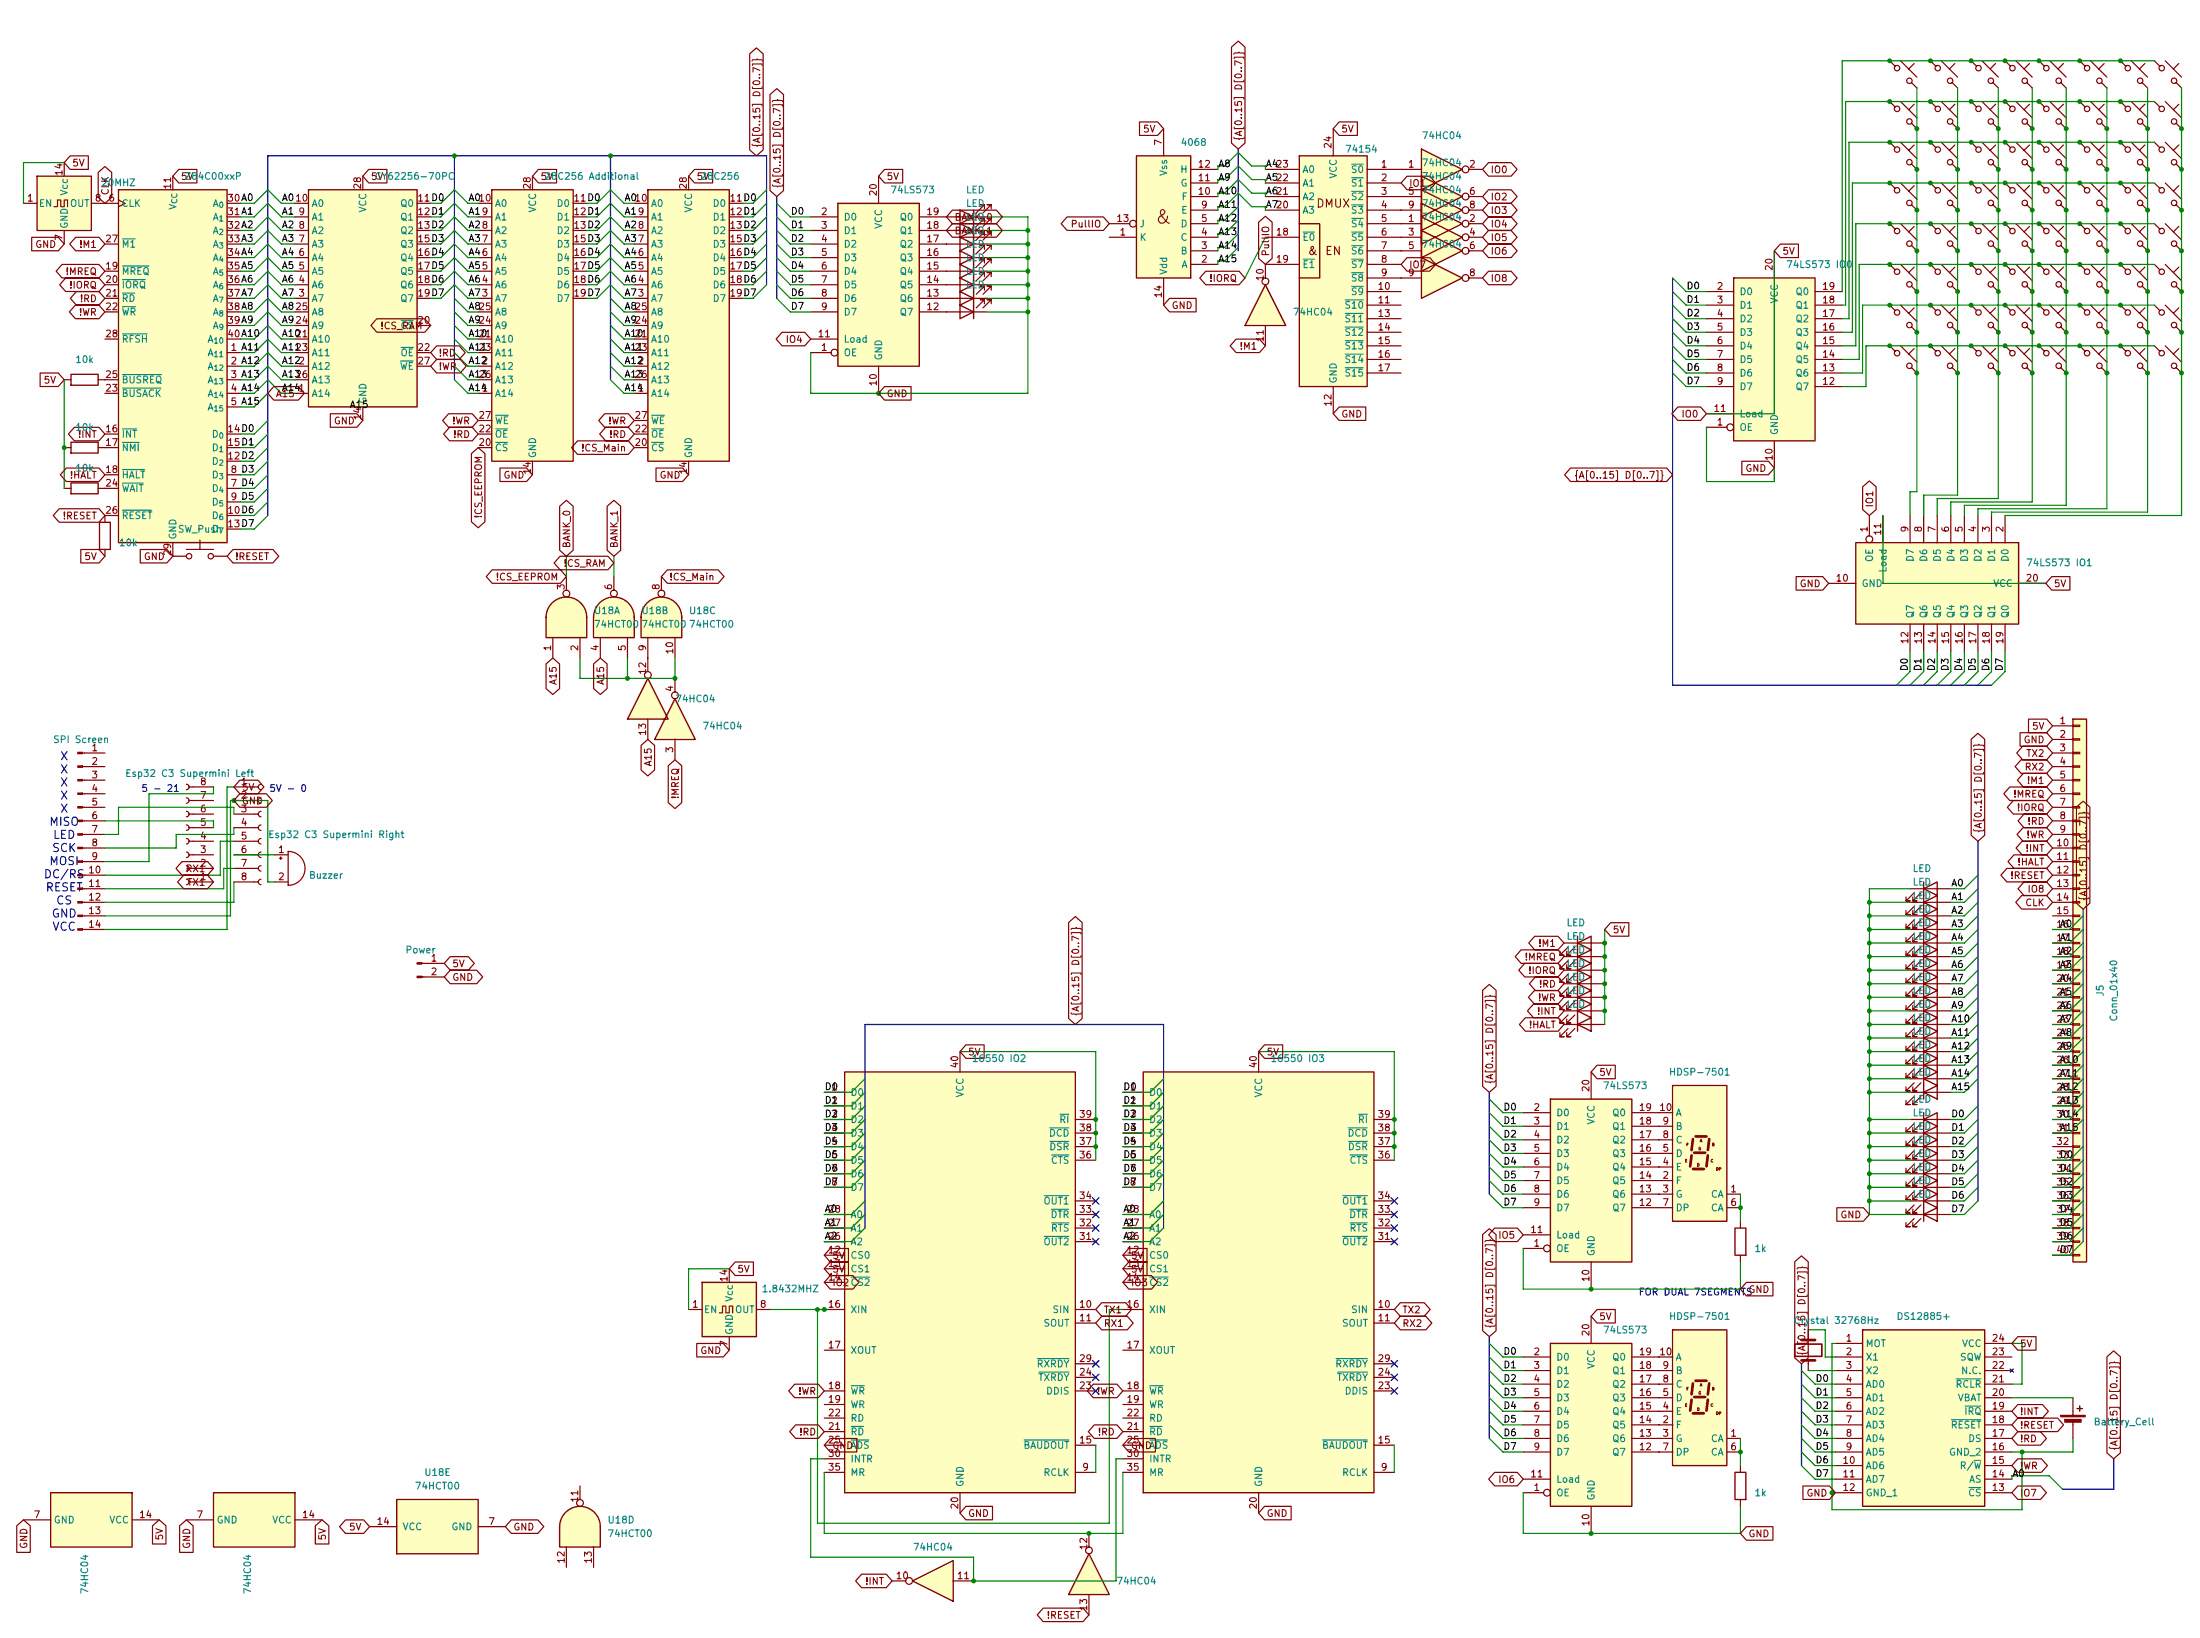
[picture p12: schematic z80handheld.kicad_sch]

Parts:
BT1: Battery_Cell; BatteryHolder_MYOUNG_BS-07-A1BJ001_CR2032
BZ1: Buzzer; Buzzer_12x9.5RM7.6
D1, D2, D3, D4, D5, D6, D7, D8, D9, D10, D11, D12, D13, D14, D15, D16, D17, D18, D19, D20, D21, D22, D23, D24, D25, D26, D27, D28, D29, D30, D31, D32, D33, D34, D35, D36, D37, D38, D39: LED; LED_1206_3216Metric_Pad1.42x1.75mm_HandSolder
IC1: DS12885+; DIP1524W51P254L3175H508Q24N; Manufacturer_Part_Number DS12885+; Mouser Part Number 700-DS12885
J1: Power; PinHeader_1x02_P2.54mm_Vertical
J2: Esp32 C3 Supermini Right; PinHeader_1x08_P2.54mm_Vertical
J3: SPI Screen; PinHeader_1x14_P2.54mm_Vertical
J4: Esp32 C3 Supermini Left; PinHeader_1x08_P2.54mm_Vertical
J5: Conn_01x40; PinHeader_1x40_P2.54mm_Vertical
R1, R2, R3, R5: 10k; R_Axial_DIN0207_L6.3mm_D2.5mm_P7.62mm_Horizontal
R4, R6: 1k; R_Axial_DIN0207_L6.3mm_D2.5mm_P7.62mm_Horizontal
SW1, SW2, SW3, SW4, SW5, SW6, SW7, SW8, SW9, SW10, SW11, SW12, SW13, SW14, SW15, SW16, SW17, SW18, SW19, SW20, SW21, SW22, SW23, SW24, SW25, SW26, SW27, SW28, SW29, SW30, SW31, SW32, SW33, SW34, SW35, SW36, SW37, SW38, SW39, SW40, SW41, SW42, SW43, SW44, SW45, SW46, SW47, SW48, SW49, SW50, SW51, SW52, SW53, SW54, SW55, SW56, SW57, SW58, SW59, SW60, SW61, SW62, SW63, SW64: SW_Push_45deg; SW_SPST_PTS810
SW65: SW_Push; SW_PUSH_6mm
U1, U3: 74HC04; DIP-14_W7.62mm
U2: 4068; DIP-14_W7.62mm
U4: 74154; DIP-24_W7.62mm
U5: 74LS573 IO0; DIP-20_W7.62mm
U6, U13, U15: 74LS573; DIP-20_W7.62mm
U7: CY62256-70PC; DIP_Socket-28_W6.9mm_W7.62mm_W10.16mm_W12.7mm_W13.5mm_3M_22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
U8: 28C256 Additional; DIP_Socket-28_W6.9mm_W7.62mm_W10.16mm_W12.7mm_W13.5mm_3M_22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
U9: 28C256; DIP_Socket-28_W6.9mm_W7.62mm_W10.16mm_W12.7mm_W13.5mm_3M_22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
U10: Z84C00xxP; DIP-40_W15.24mm
U11: 74LS573 IO1; DIP-20_W7.62mm
U12, U14: HDSP-7501; 7SegmentLED_LTS6760_LTS6780
U16: 16550 IO2; DIP-40_W15.24mm
U17: 16550 IO3; DIP-40_W15.24mm
U18: 74HCT00; DIP-14_W7.62mm
Y1: 20MHZ; Oscillator_DIP-14
Y2: Crystal 32768Hz; Crystal_C38-LF_D3.0mm_L8.0mm_Vertical
Y3: 1.8432MHZ; Oscillator_DIP-14

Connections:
5V: D6.2 (A), D9.2 (A), D12.2 (A), D15.2 (A), D18.2 (A), D21.2 (A), D24.2 (A), IC1.21 (~RCLR), IC1.24 (VCC), J1.1, J2.1, J3.14, J5.1, R1.1, R2.1, R3.1, R5.2, U1.2, U1.14 (VCC), U2.7 (Vss), U3.14 (VCC), U4.24 (VCC), U5.11 (Load), U5.20 (VCC), U6.20 (VCC), U7.28 (VCC), U8.28 (VCC), U9.28 (VCC), U10.11 (V_{CC}), U11.11 (Load), U11.20 (VCC), U13.20 (VCC), U15.20 (VCC), U16.12 (CS0), U16.13 (CS1), U16.36 (~CTS), U16.37 (~DSR), U16.38 (~DCD), U16.39 (~RI), U16.40 (VCC), U17.12 (CS0), U17.13 (CS1), U17.36 (~CTS), U17.37 (~DSR), U17.38 (~DCD), U17.39 (~RI), U17.40 (VCC), U18.14 (VCC), Y1.1 (EN), Y1.14 (Vcc), Y3.1 (EN), Y3.14 (Vcc)
!CS_EEPROM: D3.2 (A), U6.19 (Q0), U8.20 (~CS), U18.3
!CS_Main: U9.20 (~CS), U18.8
!CS_RAM: D5.2 (A), U6.18 (Q1), U7.20 (~CS), U18.6
!HALT: D6.1 (K), J5.11, U10.18 (~HALT)
!INT: D9.1 (K), IC1.19 (~IRQ), J5.10, U3.10, U10.16 (~INT)
!IORQ: D18.1 (K), J5.7, U4.18 (~E0), U10.20 (~IORQ)
!M1: D24.1 (K), J5.5, U1.11, U10.27 (~M1)
!MREQ: D21.1 (K), J5.6, U1.3, U10.19 (~MREQ)
!RD: D15.1 (K), IC1.17 (DS), J5.8, U7.22 (~OE), U8.22 (~OE), U9.22 (~OE), U10.21 (~RD), U16.21 (~RD), U17.21 (~RD)
!RESET: IC1.18 (~RESET), J5.12, R5.1, SW65.2, U3.13, U10.26 (~RESET)
!WR: D12.1 (K), IC1.15 (R/~W), J5.9, U7.27 (~WE), U8.27 (~WE), U9.27 (~WE), U10.22 (~WR), U16.18 (~WR), U17.18 (~WR)
/A0: D1.2 (A), IC1.14 (AS), J5.16, U7.10 (A0), U8.10 (A0), U9.10 (A0), U10.30 (A_{0}), U16.28 (A0), U17.28 (A0)
/A1: D2.2 (A), J5.17, U7.9 (A1), U8.9 (A1), U9.9 (A1), U10.31 (A_{1}), U16.27 (A1), U17.27 (A1)
/A2: D4.2 (A), J5.18, U7.8 (A2), U8.8 (A2), U9.8 (A2), U10.32 (A_{2}), U16.26 (A2), U17.26 (A2)
/A3: D7.2 (A), J5.19, U7.7 (A3), U8.7 (A3), U9.7 (A3), U10.33 (A_{3})
/A4: D10.2 (A), J5.20, U4.23 (A0), U7.6 (A4), U8.6 (A4), U9.6 (A4), U10.34 (A_{4})
/A5: D13.2 (A), J5.21, U4.22 (A1), U7.5 (A5), U8.5 (A5), U9.5 (A5), U10.35 (A_{5})
/A6: D16.2 (A), J5.22, U4.21 (A2), U7.4 (A6), U8.4 (A6), U9.4 (A6), U10.36 (A_{6})
/A7: D19.2 (A), J5.23, U4.20 (A3), U7.3 (A7), U8.3 (A7), U9.3 (A7), U10.37 (A_{7})
/A8: D22.2 (A), J5.24, U2.12 (H), U7.25 (A8), U8.25 (A8), U9.25 (A8), U10.38 (A_{8})
/A9: D25.2 (A), J5.25, U2.11 (G), U7.24 (A9), U8.24 (A9), U9.24 (A9), U10.39 (A_{9})
/A10: D26.2 (A), J5.26, U2.10 (F), U7.21 (A10), U8.21 (A10), U9.21 (A10), U10.40 (A_{10})
/A11: D27.2 (A), J5.27, U2.9 (E), U7.23 (A11), U8.23 (A11), U9.23 (A11), U10.1 (A_{11})
/A12: D28.2 (A), J5.28, U2.5 (D), U7.2 (A12), U8.2 (A12), U9.2 (A12), U10.2 (A_{12})
/A13: D29.2 (A), J5.29, U2.4 (C), U7.26 (A13), U8.26 (A13), U9.26 (A13), U10.3 (A_{13})
/A14: D30.2 (A), J5.30, U2.3 (B), U7.1 (A14), U8.1 (A14), U9.1 (A14), U10.4 (A_{14})
/D0: D32.2 (A), IC1.4 (AD0), J5.33, U5.2 (D0), U6.2 (D0), U7.11 (Q0), U8.11 (D0), U9.11 (D0), U10.14 (D_{0}), U11.12 (Q7), U13.2 (D0), U15.2 (D0), U16.1 (D0), U17.1 (D0)
/D1: D33.2 (A), IC1.5 (AD1), J5.34, U5.3 (D1), U6.3 (D1), U7.12 (Q1), U8.12 (D1), U9.12 (D1), U10.15 (D_{1}), U11.13 (Q6), U13.3 (D1), U15.3 (D1), U16.2 (D1), U17.2 (D1)
/D2: D34.2 (A), IC1.6 (AD2), J5.35, U5.4 (D2), U6.4 (D2), U7.13 (Q2), U8.13 (D2), U9.13 (D2), U10.12 (D_{2}), U11.14 (Q5), U13.4 (D2), U15.4 (D2), U16.3 (D2), U17.3 (D2)
/D3: D35.2 (A), IC1.7 (AD3), J5.36, U5.5 (D3), U6.5 (D3), U7.15 (Q3), U8.15 (D3), U9.15 (D3), U10.8 (D_{3}), U11.15 (Q4), U13.5 (D3), U15.5 (D3), U16.4 (D3), U17.4 (D3)
/D4: D36.2 (A), IC1.8 (AD4), J5.37, U5.6 (D4), U6.6 (D4), U7.16 (Q4), U8.16 (D4), U9.16 (D4), U10.7 (D_{4}), U11.16 (Q3), U13.6 (D4), U15.6 (D4), U16.5 (D4), U17.5 (D4)
/D5: D37.2 (A), IC1.9 (AD5), J5.38, U5.7 (D5), U6.7 (D5), U7.17 (Q5), U8.17 (D5), U9.17 (D5), U10.9 (D_{5}), U11.17 (Q2), U13.7 (D5), U15.7 (D5), U16.6 (D5), U17.6 (D5)
/D6: D38.2 (A), IC1.10 (AD6), J5.39, U5.8 (D6), U6.8 (D6), U7.18 (Q6), U8.18 (D6), U9.18 (D6), U10.10 (D_{6}), U11.18 (Q1), U13.8 (D6), U15.8 (D6), U16.7 (D6), U17.7 (D6)
/D7: D39.2 (A), IC1.11 (AD7), J5.40, U5.9 (D7), U6.9 (D7), U7.19 (Q7), U8.19 (D7), U9.19 (D7), U10.13 (D_{7}), U11.19 (Q0), U13.9 (D7), U15.9 (D7), U16.8 (D7), U17.8 (D7)
A15: D31.2 (A), J5.31, U1.13, U2.2 (A), U10.5 (A_{15}), U18.1, U18.4
CLK: J5.14, U10.6 (CLK), Y1.8 (OUT)
GND: BT1.2 (-), BZ1.2 (-), D1.1 (K), D2.1 (K), D3.1 (K), D4.1 (K), D5.1 (K), D7.1 (K), D8.1 (K), D10.1 (K), D11.1 (K), D13.1 (K), D14.1 (K), D16.1 (K), D17.1 (K), D19.1 (K), D20.1 (K), D22.1 (K), D23.1 (K), D25.1 (K), D26.1 (K), D27.1 (K), D28.1 (K), D29.1 (K), D30.1 (K), D31.1 (K), D32.1 (K), D33.1 (K), D34.1 (K), D35.1 (K), D36.1 (K), D37.1 (K), D38.1 (K), D39.1 (K), IC1.1 (MOT), IC1.12 (GND_1), IC1.16 (GND_2), J1.2, J2.2, J3.13, J5.2, R4.1, R6.1, SW65.1, U1.7 (GND), U2.14 (Vdd), U3.7 (GND), U4.12 (GND), U5.1 (OE), U5.10 (GND), U6.1 (OE), U6.10 (GND), U7.14 (GND), U8.14 (GND), U9.14 (GND), U10.29 (GND), U11.10 (GND), U13.1 (OE), U13.10 (GND), U15.1 (OE), U15.10 (GND), U16.20 (GND), U16.25 (~ADS), U17.20 (GND), U17.25 (~ADS), U18.7 (GND), Y1.7 (GND), Y3.7 (GND)
IO1: U4.2 (~S1), U11.1 (OE)
IO2: U1.6, U16.14 (~CS2)
IO3: U1.8, U17.14 (~CS2)
IO4: U3.2, U6.11 (Load)
IO5: U3.4, U13.11 (Load)
IO6: U3.6, U15.11 (Load)
IO7: IC1.13 (~CS), U4.8 (~S7)
IO8: J5.13, U3.8
unnamed: BT1.1 (+), IC1.20 (VBAT)
unnamed: BZ1.1 (+), J2.6
unnamed: D8.2 (A), U6.17 (Q2)
unnamed: D11.2 (A), U6.16 (Q3)
unnamed: D14.2 (A), U6.15 (Q4)
unnamed: D17.2 (A), U6.14 (Q5)
unnamed: D20.2 (A), U6.13 (Q6)
unnamed: D23.2 (A), U6.12 (Q7)
unnamed: IC1.2 (X1), Y2.2
unnamed: IC1.3 (X2), Y2.1
unnamed: J2.3, J3.7
unnamed: J2.4, J3.8
unnamed: J2.5, J3.10
unnamed: J2.7, J3.11
unnamed: J2.8, J3.12
unnamed: J3.6, J4.5
unnamed: J3.9, J4.8
unnamed: R4.2, U12.1 (CA), U12.6 (CA)
unnamed: R6.2, U14.1 (CA), U14.6 (CA)
unnamed: U1.4, U18.2, U18.5, U18.10
unnamed: U1.12, U18.9
unnamed: U1.1, U4.1 (~S0)
unnamed: U1.5, U4.3 (~S2)
unnamed: U1.9, U4.4 (~S3)
unnamed: U3.1, U4.5 (~S4)
unnamed: U3.3, U4.6 (~S5)
unnamed: U3.5, U4.7 (~S6)
unnamed: U3.9, U4.9 (~S8)
unnamed: SW1.1, SW2.1, SW3.1, SW4.1, SW5.1, SW6.1, SW7.1, SW8.1, U5.19 (Q0)
unnamed: SW9.1, SW10.1, SW11.1, SW12.1, SW13.1, SW14.1, SW15.1, SW16.1, U5.18 (Q1)
unnamed: SW17.1, SW18.1, SW19.1, SW20.1, SW21.1, SW22.1, SW23.1, SW24.1, U5.17 (Q2)
unnamed: SW25.1, SW26.1, SW27.1, SW28.1, SW29.1, SW30.1, SW31.1, SW32.1, U5.16 (Q3)
unnamed: SW33.1, SW34.1, SW35.1, SW36.1, SW37.1, SW38.1, SW39.1, SW40.1, U5.15 (Q4)
unnamed: SW41.1, SW42.1, SW43.1, SW44.1, SW45.1, SW46.1, SW47.1, SW48.1, U5.14 (Q5)
unnamed: SW49.1, SW50.1, SW51.1, SW52.1, SW53.1, SW54.1, SW55.1, SW56.1, U5.13 (Q6)
unnamed: SW57.1, SW58.1, SW59.1, SW60.1, SW61.1, SW62.1, SW63.1, SW64.1, U5.12 (Q7)
unnamed: R1.2, U10.25 (~BUSREQ)
unnamed: R2.2, U10.17 (~NMI)
unnamed: R3.2, U10.24 (~WAIT)
unnamed: SW8.2, SW16.2, SW24.2, SW32.2, SW40.2, SW48.2, SW56.2, SW64.2, U11.2 (D0)
unnamed: SW7.2, SW15.2, SW23.2, SW31.2, SW39.2, SW47.2, SW55.2, SW63.2, U11.3 (D1)
unnamed: SW6.2, SW14.2, SW22.2, SW30.2, SW38.2, SW46.2, SW54.2, SW62.2, U11.4 (D2)
unnamed: SW5.2, SW13.2, SW21.2, SW29.2, SW37.2, SW45.2, SW53.2, SW61.2, U11.5 (D3)
unnamed: SW4.2, SW12.2, SW20.2, SW28.2, SW36.2, SW44.2, SW52.2, SW60.2, U11.6 (D4)
unnamed: SW3.2, SW11.2, SW19.2, SW27.2, SW35.2, SW43.2, SW51.2, SW59.2, U11.7 (D5)
unnamed: SW2.2, SW10.2, SW18.2, SW26.2, SW34.2, SW42.2, SW50.2, SW58.2, U11.8 (D6)
unnamed: SW1.2, SW9.2, SW17.2, SW25.2, SW33.2, SW41.2, SW49.2, SW57.2, U11.9 (D7)
unnamed: U12.10 (A), U13.19 (Q0)
unnamed: U12.9 (B), U13.18 (Q1)
unnamed: U12.8 (C), U13.17 (Q2)
unnamed: U12.5 (D), U13.16 (Q3)
unnamed: U12.7 (DP), U13.12 (Q7)
unnamed: U12.4 (E), U13.15 (Q4)
unnamed: U12.2 (F), U13.14 (Q5)
unnamed: U12.3 (G), U13.13 (Q6)
unnamed: U14.10 (A), U15.19 (Q0)
unnamed: U14.9 (B), U15.18 (Q1)
unnamed: U14.8 (C), U15.17 (Q2)
unnamed: U14.5 (D), U15.16 (Q3)
unnamed: U14.7 (DP), U15.12 (Q7)
unnamed: U14.4 (E), U15.15 (Q4)
unnamed: U14.2 (F), U15.14 (Q5)
unnamed: U14.3 (G), U15.13 (Q6)
unnamed: U3.11, U16.30 (INTR), U17.30 (INTR)
unnamed: U3.12, U16.35 (MR), U17.35 (MR)
unnamed: U16.9 (RCLK), U16.15 (~BAUDOUT)
unnamed: U16.16 (XIN), U17.16 (XIN), Y3.8 (OUT)
unnamed: U17.9 (RCLK), U17.15 (~BAUDOUT)
PullIO: U1.10, U2.13 (J), U4.19 (~E1)
RX1: J4.2, U16.11 (SOUT)
RX2: J5.4, U17.11 (SOUT)
TX1: J4.1, U16.10 (SIN)
TX2: J5.3, U17.10 (SIN)

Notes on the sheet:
5V - 0
FOR DUAL 7SEGMENTS
5 - 21
X X X X X MISO LED SCK MOSI DC/RS RESET CS GND VCC

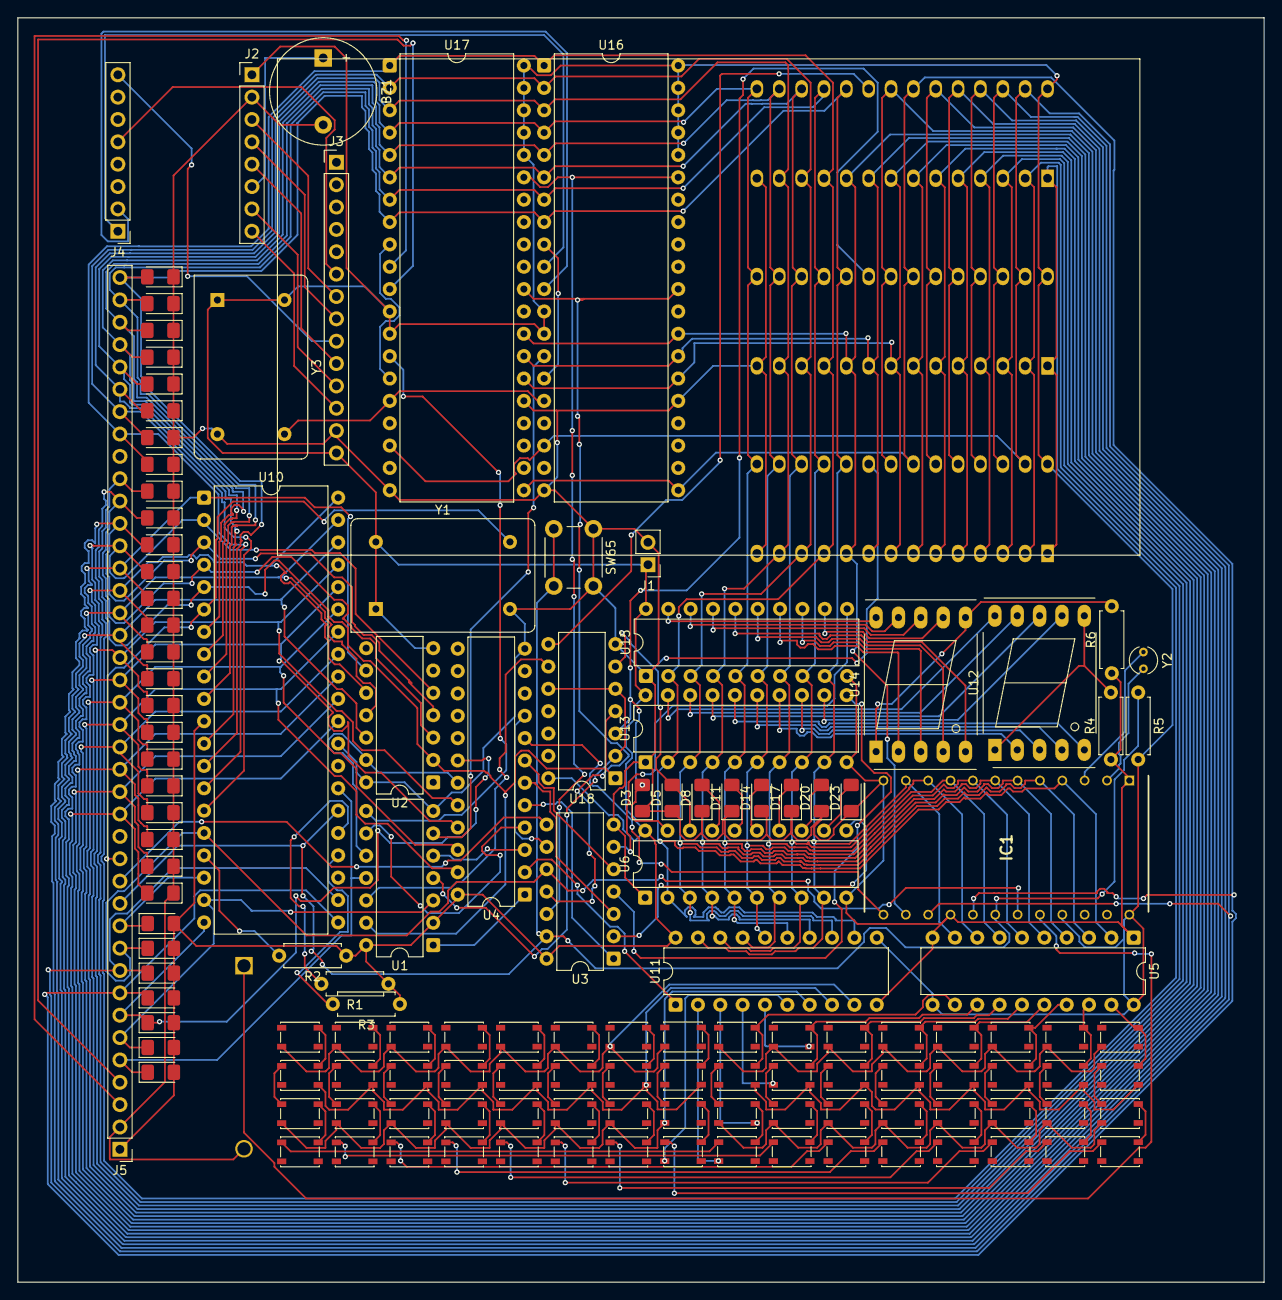
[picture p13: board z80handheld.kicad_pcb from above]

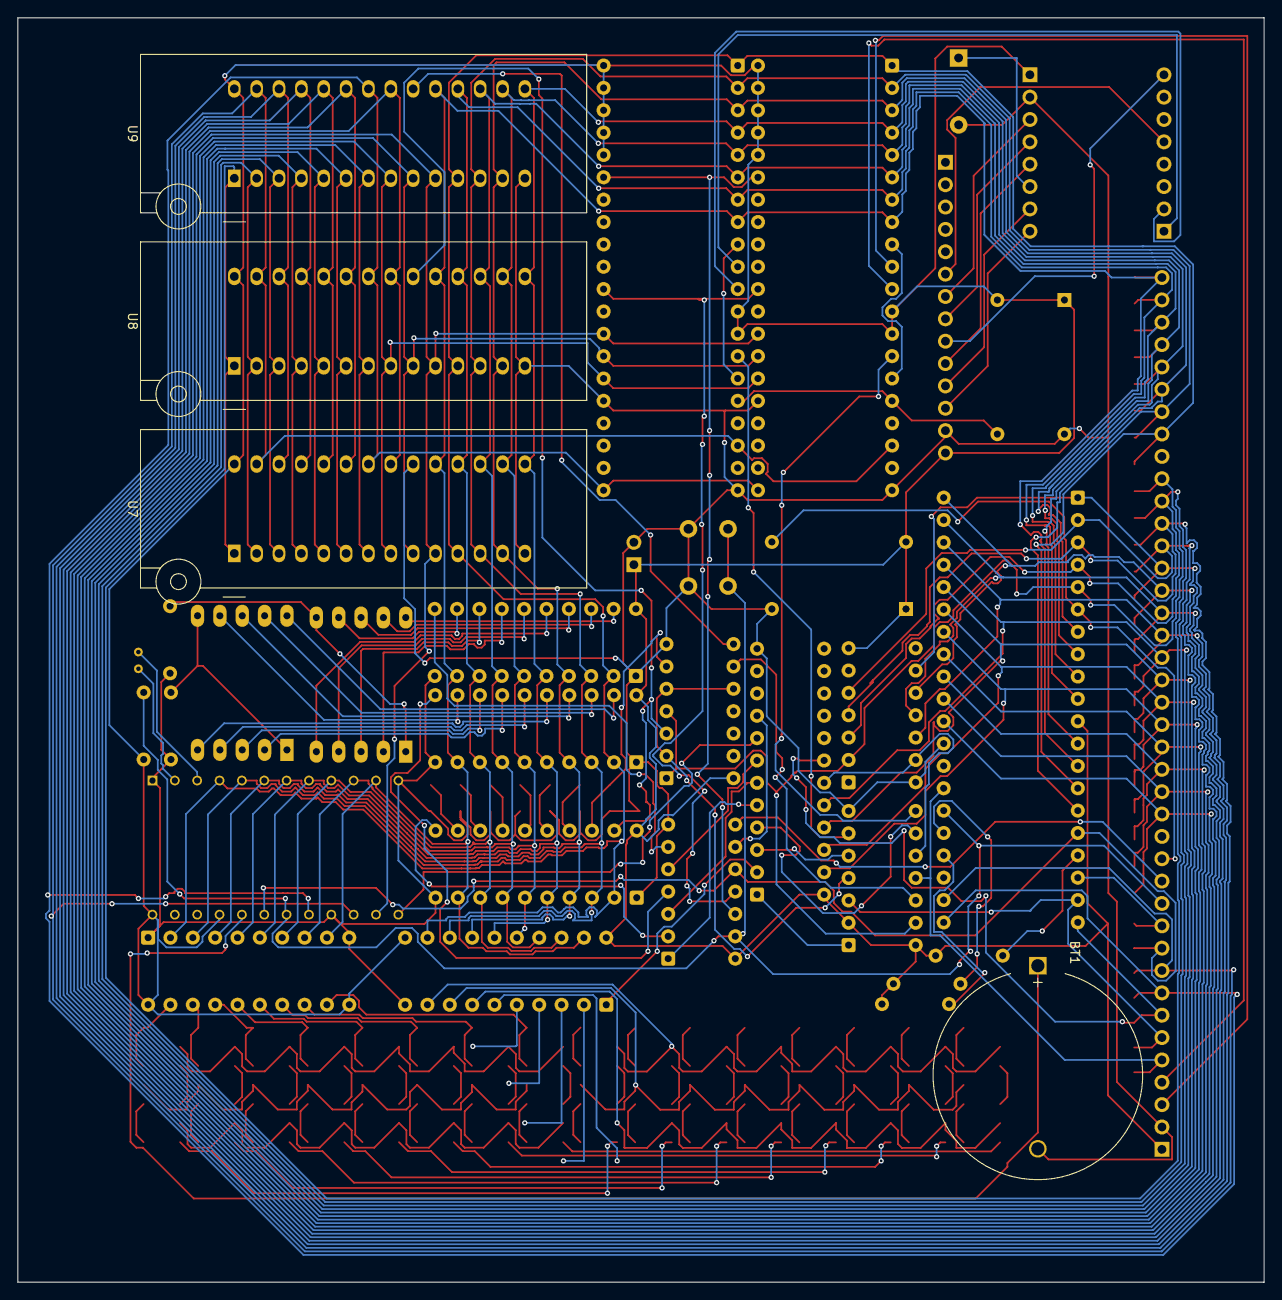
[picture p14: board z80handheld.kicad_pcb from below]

Board: 2 copper layers, 141.6 x 143.7 mm, 139 parts (4 on the bottom side), 119 nets.

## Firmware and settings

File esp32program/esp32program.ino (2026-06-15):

#define RXD1 21
#define TXD1 20
#include <TFT_eSPI.h>
//#define LOAD_FONT2   pls copy this to TFT_eSPI User_Setup.h
//#define TFT_MISO 8
//#define TFT_MOSI 5
//#define TFT_SCLK 4
//#define TFT_CS 0
//#define TFT_DC 3
//#define TFT_RST 1
TFT_eSPI tft = TFT_eSPI();
uint8_t posx = 0; //16/480
uint8_t posy = 0; //16/320
void setup() {
  tft.init();
  tft.setRotation(1);
  tft.fillScreen(TFT_BLACK);
  tft.setTextColor(TFT_WHITE,TFT_BLACK);

  Serial.begin(115200);
  Serial1.begin(9600, SERIAL_8N1, RXD1, TXD1);
}
bool is_printable_ascii(int ch) {
    return (ch >= 32 && ch <= 126);
}
void loop() {
  if (Serial1.available()) {
    char rc;
    rc = Serial1.read();
    if (is_printable_ascii(rc));
      tft.setTextFont(2);
      tft.drawString(rc, posx * 16, posy * 16);
      posx++;
      if (posx >= 30){
        posx = 0;
        posy++;
      }
      if (posy >= 20){
        posy = 20;      //erm yah currently no scrolling function available :|
      }
    }
    Serial.write(rc);
  }
  if (Serial.available()) {
    Serial1.write(Serial.read());
  }
}

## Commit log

2026-04-25 Rename 螢幕擷取畫面 (103).png to design.png
2026-04-25 Rename 螢幕擷取畫面 (107).png to Route.png
2026-04-25 Rename 螢幕擷取畫面 (110).png to PCB.png
2026-05-07 Add LoadFromAToB assembly routine
    This assembly code loads data from one memory location to another using a loop.
